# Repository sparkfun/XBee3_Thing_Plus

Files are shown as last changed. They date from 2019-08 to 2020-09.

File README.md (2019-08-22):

SparkFun XBee3 Thing Plus
========================================

<table class="table table-hover table-striped table-bordered">
  <tr align="center">
   <td><a href="https://www.sparkfun.com/products/15435">SparkFun XBee3 Thing Plus (u.FL)</a></td>
   <td><a href="https://www.sparkfun.com/products/15454">SparkFun XBee3 Thing Plus (PCB Antenna)</a></td>
  </tr>
  <tr align="center">
   <td><i>SparkFun XBee3 Thing Plus (u.FL) [<a href="https://www.sparkfun.com/products/15435">WRL-15435</a>]</i></td>
   <td><i>SparkFun XBee3 Thing Plus (PCB Antenna) [<a href="https://www.sparkfun.com/products/15454">WRL-15454</a>]</i></td>
  </tr>
</table>

The XBee3 Thing Plus is an ultra capable and easy way for getting into wireless device development. The combination of XBee and Qwiic in a space conscious design represents a much needed update to our XBee offering. With 20 I/O pins and Lithium Polymer Ion battery management, the XBee3 Thing Plus has all the basics for quickly prototyping or developing a connected device such as a remote sensor. The Qwiic connector and JST connector for the battery make for a solder-less option when working with the board which shortens setup time.

The new XBee3 Micro Module provides the classic all-but plug and play 802.15.4 2.4GHz wireless connection (Zigbee 3.0 Protocol) that makes it so desirable, but with a new addition of being programmable with MicroPython (32KB of memory available for it). RF data rates up to 250 Kbps and 200ft indoor ranges and up to 4000ft line-of-sight outdoor range. Communicating with/Configuring the module happens via an AT Command set or the Digi API, X-CTU, both locally or over-the-air. There's even a mobile version of X-CTU now; Digi XBee® Mobile.

This variation features a U.FL antenna connector for longer range communications.

Repository Contents
-------------------

* **/Hardware** - Eagle design files (.brd, .sch)

Documentation
--------------
* **[Hookup Guide](https://learn.sparkfun.com/tutorials/xbee3-thing-plus-hookup-guide)** - Basic hookup guide for the XBee Thing Plus.
* **[SparkFun Fritzing repo](https://github.com/sparkfun/Fritzing_Parts)** - Fritzing diagrams for SparkFun products.

License Information
-------------------

This product is _**open source**_! 

Please review the LICENSE.md file for license information. 

If you have any questions or concerns on licensing, please contact technical support on our [SparkFun forums](https://forum.sparkfun.com/viewforum.php?f=152).

Distributed as-is; no warranty is given.

- Your friends at SparkFun.

_<COLLABORATION CREDIT>_

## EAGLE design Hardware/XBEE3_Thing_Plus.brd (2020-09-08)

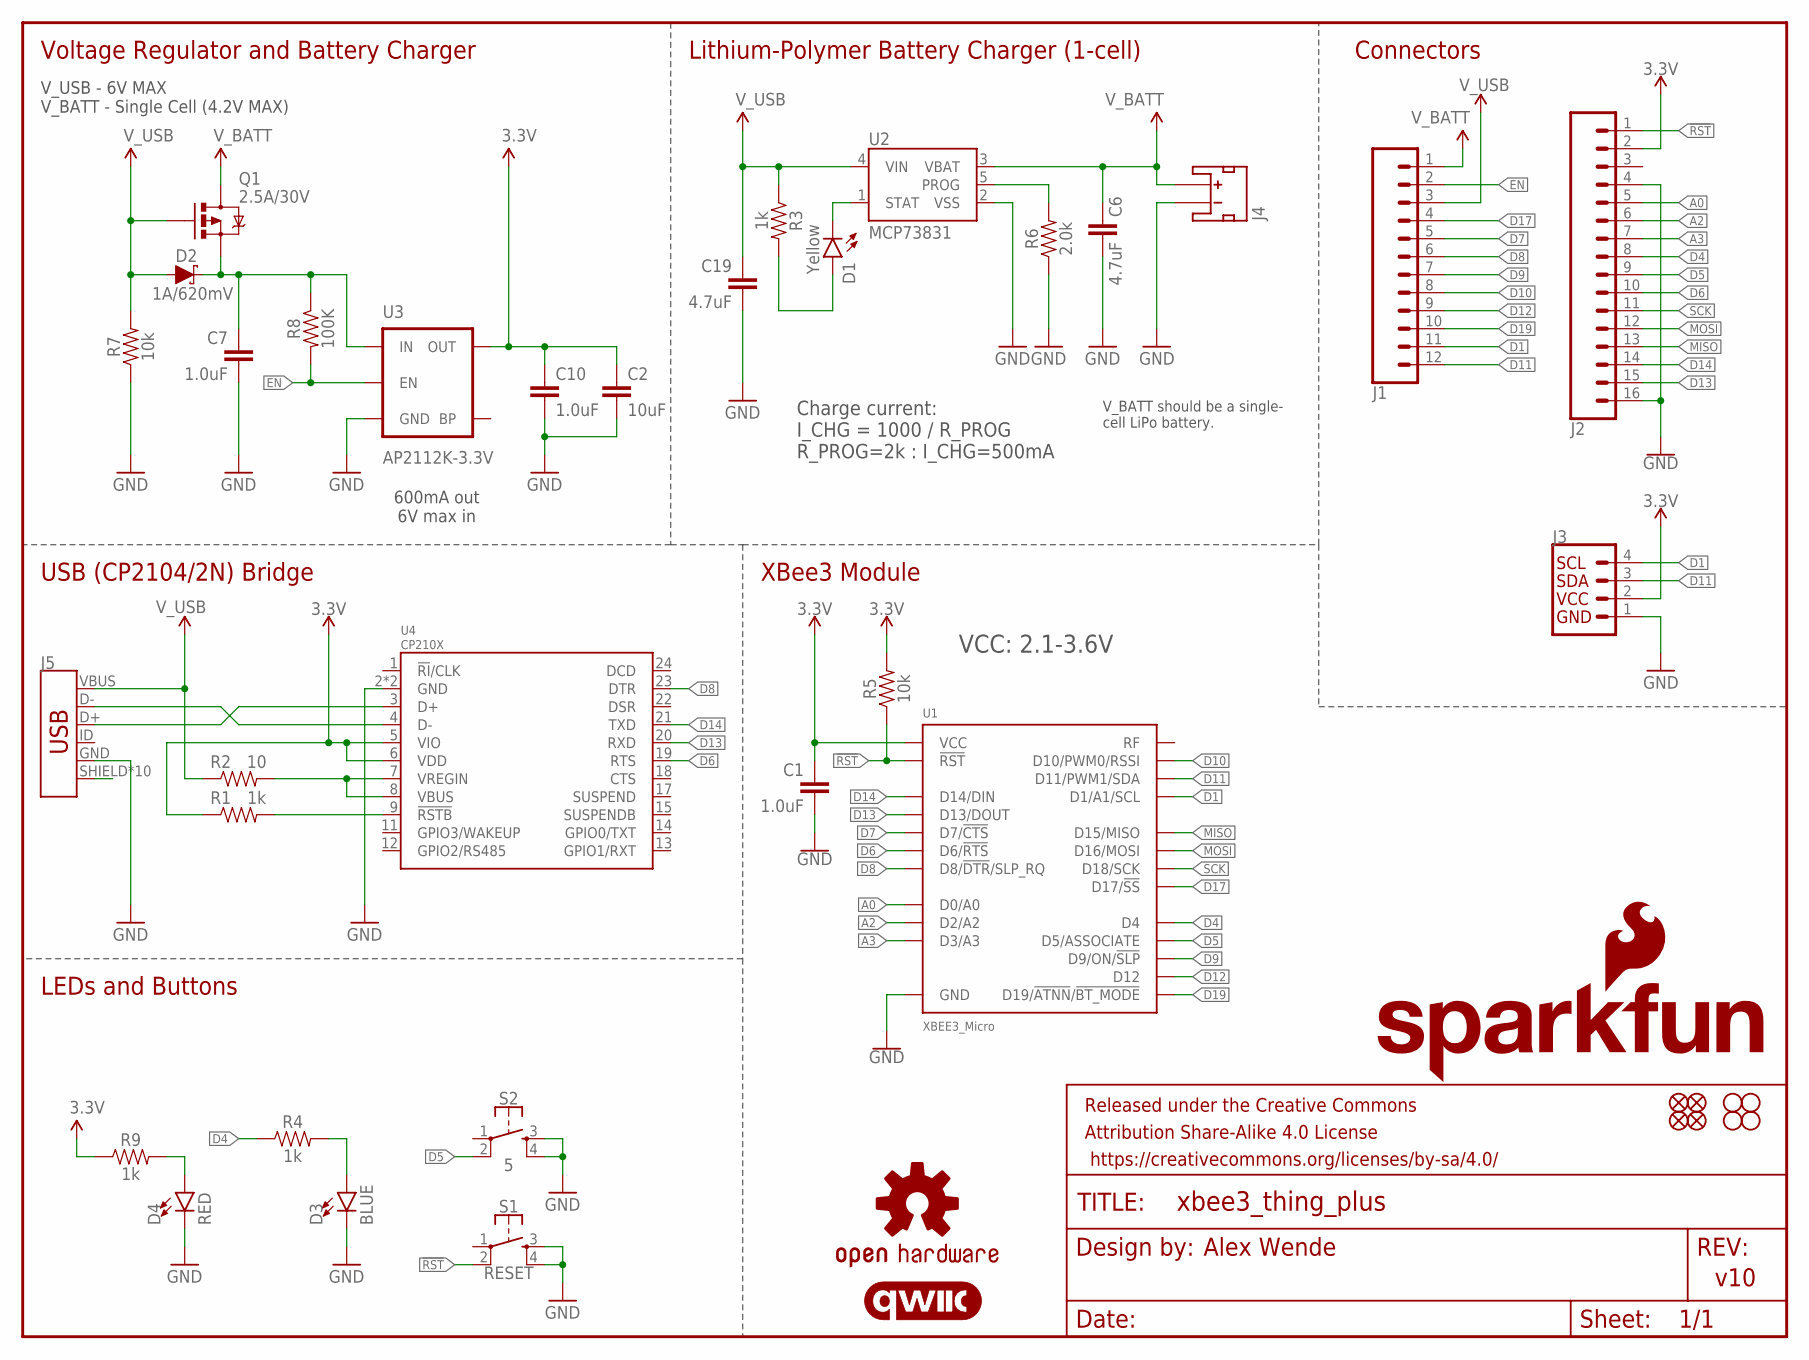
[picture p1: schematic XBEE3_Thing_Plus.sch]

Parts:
C1, C7: 1.0uF; 0603
C2: 10uF; 0603
C6, C19: 4.7uF; 0603
C10: 1.0uF; 0402
D1: Yellow; LED-0603
D2: 1A/620mV; SOD-323
D3: BLUE; LED-0603
D4: RED; LED-0603
FD1, FD2, FD3, FD4: FIDUCIALUFIDUCIAL; FIDUCIAL-MICRO
FRAME1: FRAME-LETTER; CREATIVE_COMMONS
H1, H2, H3, H4: STAND-OFF
J1: CONN_12SM_SQ_NO_SILK; 1X12_SM_SQ_NOSILK
J2: CONN_161X16_SM_SQ_NOSILK; 1X16_SM_SQ_NOSILK
J3: QWIIC_CONNECTORJS-1MM; JST04_1MM_RA
J4: JST_2MM_MALE; JST-2-SMD
J5: USB_MICRO-B_HALF_PTH_MILL; USB-MICROB-PTH-MILL
LOGO1: SFE_LOGO_NAME_FLAME.1_INCH; SFE_LOGO_NAME_FLAME_.1
LOGO2: OSHW-LOGOS; OSHW-LOGO-S
Q1: 2.5A/30V; SOT23-3@1
R1, R3, R4, R9: 1k; 0603
R2: 10; 0603
R5, R7: 10k; 0603
R6: 2.0k; 0603
R8: 100K; 0402
S1: RESET; TACTILE_SWITCH_SMD_4.6X2.8MM
S2: 5; TACTILE_SWITCH_SMD_4.6X2.8MM
U1: XBEE3_Micro; XBEE3
U2: MCP73831; SOT23-5
U3: AP2112K-3.3V; SOT23-5
U4: CP210X; QFN24
U$63: QWIIC_LOGO_5MM; QWIIC_5MM

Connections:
3.3V: C1.1, C2.1, C10.1, J2.2, J3.2, R1.1, R5.2, R9.1, U1.P$2 (VCC), U3.5 (OUT), U4.5 (VIO), U4.6 (VDD)
!RST: J2.1, R5.1, S1.2, U1.P$6 (!RST)
A0: J2.5, U1.P$31 (D0/A0)
A2: J2.6, U1.P$29 (D2/A2)
A3: J2.7, U1.P$28 (D3/A3)
CHG: D1.C, U2.1 (STAT)
D1: J1.11, J3.4, U1.P$30 (D1/A1/SCL)
D4: J2.8, R4.1, U1.P$23 (D4)
D5: J2.9, S2.2, U1.P$26 (D5/ASSOCIATE)
D6: J2.10, U1.P$27 (D6/!RTS), U4.19 (RTS)
D7: J1.5, U1.P$24 (D7/!CTS)
D8: J1.6, U1.P$9 (D8/!DTR!/SLP_RQ), U4.23 (DTR)
D9: J1.7, U1.P$25 (D9/ON/!SLP)
D10: J1.8, U1.P$7 (D10/PWM0/RSSI)
D11: J1.12, J3.3, U1.P$8 (D11/PWM1/SDA)
D12: J1.9, U1.P$5 (D12)
D13: J2.15, U1.P$3 (D13/DOUT), U4.20 (RXD)
D14: J2.14, U1.P$4 (D14/DIN), U4.21 (TXD)
D17: J1.4, U1.P$14 (D17/!SS)
D19: J1.10, U1.P$11 (D19/!ATNN!/!BT_MODE)
D+: J5.D+, U4.3 (D+)
D-: J5.D-, U4.4 (D-)
EN: J1.2, R8.2, U3.3 (EN)
GND: C1.2, C2.2, C6.2, C7.2, C10.2, C19.2, D3.C, D4.C, J2.4, J2.16, J3.1, J4.1 (-), J5.GND, R6.1, R7.1, S1.3, S1.4, S2.3, S2.4, U1.P$1 (GND), U1.P$10 (GND), U1.P$12 (GND), U1.P$21 (GND), U1.P$32 (GND), U1.P$34 (GND), U2.2 (VSS), U3.2 (GND), U4.2 (GND), U4.PAD (GND)
MISO: J2.13, U1.P$16 (D15/MISO)
MOSI: J2.12, U1.P$15 (D16/MOSI)
unnamed: C7.1, D2.C, Q1.2 (S), R8.1, U3.1 (IN)
unnamed: R1.2, U4.9 (!RSTB)
unnamed: R2.2, U4.7 (VREGIN), U4.8 (VBUS)
unnamed: D3.A, R4.2
unnamed: D4.A, R9.2
unnamed: J5.SHIELD, J5.SHIELD2 (SHIELD), J5.SHIELD3 (SHIELD), J5.SHIELD4 (SHIELD), J5.SHIELD5 (SHIELD), J5.SHIELD6 (SHIELD), J5.SHIELD7 (SHIELD), J5.SHIELD8 (SHIELD), J5.SHIELD9 (SHIELD), J5.SHIELD10 (SHIELD)
unnamed: R6.2, U2.5 (PROG)
unnamed: D1.A, R3.2
SCK: J2.11, U1.P$13 (D18/SCK)
V_BATT: C6.1, J1.1, J4.2 (+), Q1.3 (D), U2.3 (VBAT)
V_USB: C19.1, D2.A, J1.3, J5.VBUS, Q1.1 (G), R2.1, R3.1, R7.2, U2.4 (VIN)

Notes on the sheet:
Voltage Regulator and Battery Charger
600mA out 6V max in
V_USB - 6V MAX V_BATT - Single Cell (4.2V MAX)
V_BATT should be a single- cell LiPo battery.
Charge current: I_CHG = 1000 / R_PROG R_PROG=2k : I_CHG=500mA
Lithium-Polymer Battery Charger (1-cell)
Alex Wende
v10
USB (CP2104/2N) Bridge
Connectors
XBee3 Module
LEDs and Buttons
VCC: 2.1-3.6V

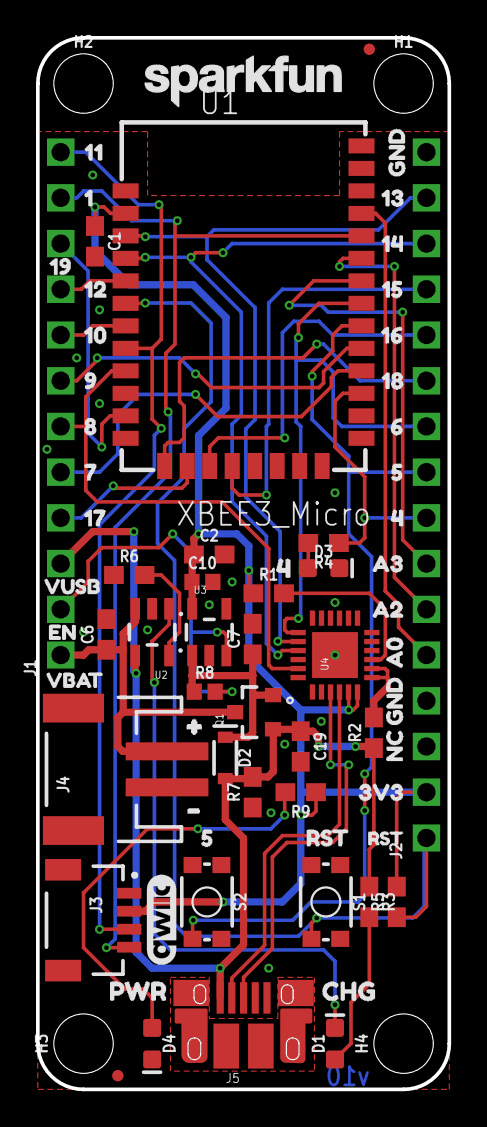
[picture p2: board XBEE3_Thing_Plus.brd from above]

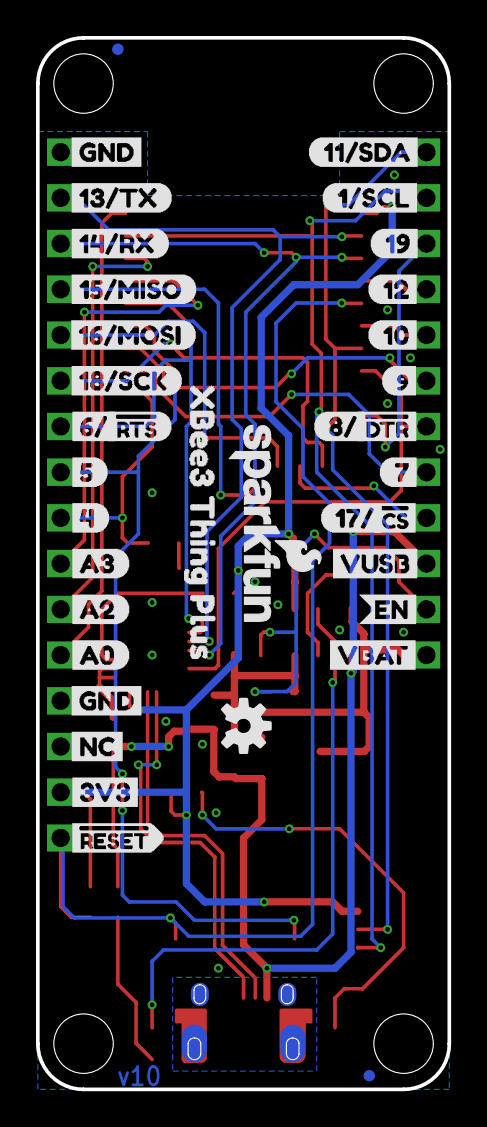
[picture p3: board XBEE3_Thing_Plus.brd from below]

Board: 2 copper layers, 22.9 x 58.4 mm, 111 parts (36 on the bottom side), 37 nets.

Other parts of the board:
U$1: #RESET0
U$2: 3V31
U$3: NC2
U$4, U$16: GND3
U$5: A04
U$6: A26
U$7: A35
U$8: 47
U$9: 58
U$11: 18#SCK10
U$12: 16#MOSI11
U$13: 15#MISO12
U$14: 14#RX13
U$15: 13#TX14
U$17: VBAT16
U$18: EN17
U$19: VUSB18
U$20: SFE_LOGO_NAME_.1
U$21: 719
U$23, U$50: 921
U$24: 1022
U$25: 1223
U$26: 1924
U$27: 1#SCL25
U$28: 11#SDA26
U$29: 170
U$30: 131
U$31: 142
U$32: 153
U$33: 164
U$34: 185
U$35: 66
U$36: 57
U$37: 48
U$38: A39
U$39: A210
U$40: A011
U$41, U$62: GND12
U$42: NC13
U$43: 3V314
U$44: #RST15
U$45: 1116
U$46: 117
U$47: 1918
U$48: 1219
U$49: 1020
U$51: 822
U$52: 723
U$54: VUSB4
U$55: EN3
U$56: PWR0
U$57: 51
U$58: RST0
U$59: 44
U$60: VBAT2
U$61: CHG1
U$64: #1
U$65: XBEE3_THING_PLUS0
U$66: #2
U$67: 6#0
U$68: #RTS1
U$69: #DTR3
U$70: 8#2
U$71: 17#4
U$72: #CS5

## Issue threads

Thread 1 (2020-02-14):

Suggestion: LED connection to the ASSOC/D5 pin

sai-ydev, 2020-02-14:
I recently purchased an XBee3 Thing Plus for my prototyping needs. I noticed that the Blue LED on board is connected to pin `D4`. It is better if it is connected to the 'D5' because the pin `D5` is actually an association indicator in its default state. When the Thing Plus is connected to the network, the blue LED would blink rapidly if it were connected to `D5`.

The button on `D5` could be connected to `D0`, which happens to be the commissioning pin or `D8` - the wake pin.

If it is okay, I can submit a pull request for the changes.

awende, 2020-02-14:
I'm going to leave this issue open so we can make this change when we revise the boards. Thanks for the suggestion!

sai-ydev, 2020-02-14:
Thanks. I forked the repo and made those changes for myself. I don't mind submitting a pull request but I understand that you probably have an internal revision process.

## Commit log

2019-06-11 v01 update
    Removed test points from bottom of the board, removed the trace antenna, and modified the top ground pour as outlined in the XBee3 datasheet
    [XBEE3_Thing_Plus.brd, XBEE3_Thing_Plus.sch]
2019-06-12 v01 Design Review Changes
    - Adjusted R2
    - Modified bottom ground pour
    - Swapped D17 and extra ground header pads
    - Updated buzzard labels
    - Rotated name and logo on bottom
    - Added SparkFun name logo to top of board
    [XBEE3_Thing_Plus.brd, XBEE3_Thing_Plus.sch]
2019-07-02 v10 design review changes
    Added input voltage range note for the XBee3 module in schematic
    [XBEE3_Thing_Plus.sch]
2019-07-02 Updated XBee3 PROD_ID
    Added the chip antenna PROD_ID along with the u.FL ID
    [XBEE3_Thing_Plus.brd, XBEE3_Thing_Plus.sch]
2020-09-08 Updated USB to UART bridge
    Update schematic to use either the CP2104 or CP2102N USB to UART bridge
    [XBEE3_Thing_Plus.brd, XBEE3_Thing_Plus.sch]

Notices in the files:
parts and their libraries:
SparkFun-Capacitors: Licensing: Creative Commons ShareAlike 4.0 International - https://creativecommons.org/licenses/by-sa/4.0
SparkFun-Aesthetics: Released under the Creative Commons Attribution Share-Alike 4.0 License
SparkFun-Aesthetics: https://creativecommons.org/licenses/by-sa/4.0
